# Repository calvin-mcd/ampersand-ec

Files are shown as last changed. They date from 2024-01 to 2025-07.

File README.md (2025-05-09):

# ampersand ec

This an open-source, experimental 2-layer EC pcb for the Ampersand keyboard designed by whitefacemountain. Ampersand is a gummyworm mounted 13.5u keyboard with minimum 40s support needed.

The firmware has been adapted by whitefacemountain and is based on [cipulot](https://cipulot.squarespace.com/)'s Menhir firmware.

## Disclaimer:

*As the Ampersand case is designed for a MX pcb using an oring, this EC pcb requires the use of [EC naevies](https://keyboardtreehouse.com/products/naevies-ec-switches) switches. Other EC switches might only work with heavy modifications of the outer housings.*

## Layout

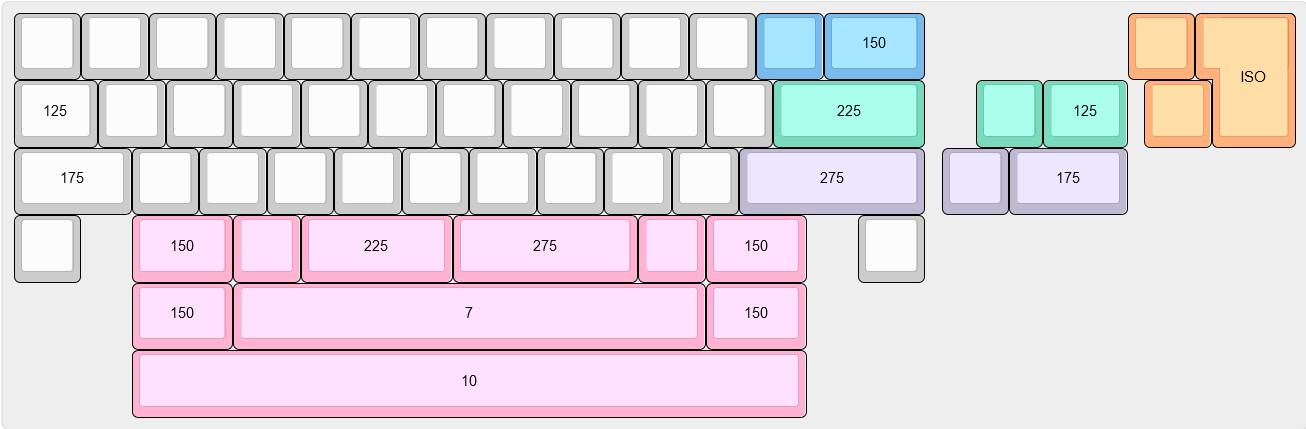
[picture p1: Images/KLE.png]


[Link](http://www.keyboard-layout-editor.com/#/gists/8dab2e8f328350c2c207f04be2b3e7d4)

There is currently only one naevies switch plate (7u, ansi, split right shift) available. More can be made available on request.

## To do

- [ ] order & test the revision (to eliminate an error with the bottom right control switch which is currently continuously triggered)

## Disclaimer

Please note that this project is a work in progress with no guarantees of a working outcome. No-one involved in this project is responsible for any usage issues that may arise. However, feel free to edit, modify and otherwise utilise these files.

## License

This project is released under the GPL v3 License. Please refer to the LICENCE file.

## Credits

As always big thanks also to the many people who inspired and helped with this board!

Any questions, contact Calvin0563 on Discord.

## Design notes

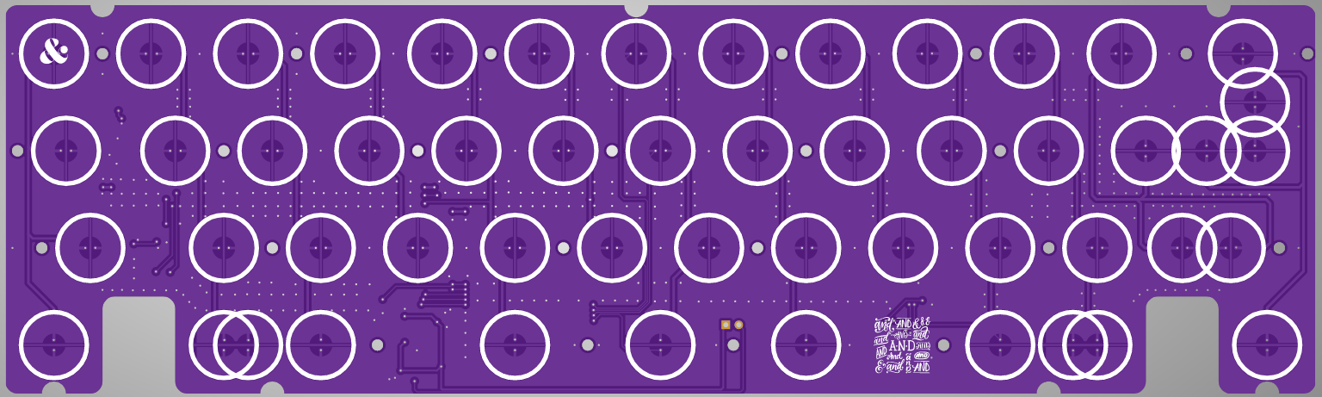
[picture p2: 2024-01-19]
Images/top.png

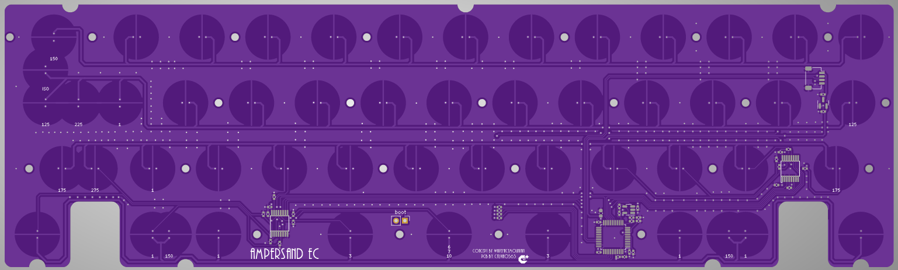
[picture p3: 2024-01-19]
Images/bottom.png

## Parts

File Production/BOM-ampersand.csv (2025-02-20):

Comment | Designator | Footprint | LCSC | Quantity
1k | R12 | R_0402_1005Metric | C11702 | 1
OPA354 | U4 | SOT-23-5 | C13388 | 1
220pF NP0 | C13 | C_0402_1005Metric | C1530 | 1
JST SH | J1 | JST_SH_SM04B-SRSS-TB_1x04-1MP_P1.00mm_Horizontal | C160404 | 1
100 | R1,R2,R3,R4 | R_0402_1005Metric | C25076 | 4
100k | R10,R11,R14,R15,R16,R17,R18,R19,R20,R21,R6,R7,R8,R9 | R_0402_1005Metric | C25741 | 14
10k | R5 | R_0402_1005Metric | C25744 | 1
100nF | C1,C11,C12,C14,C2,C3,C4,C6,C8 | C_0402_1005Metric | C307331 | 9
1uF | C10,C7,C9 | C_0402_1005Metric | C52923 | 3
XC6206PxxxMR-Regulator_Linear | U2 | SOT-23 | C5446 | 1
74HC4051 | U3,U5 | TSSOP16 | C5645 | 2
STM32F072CBT6 | U1 | LQFP-48_7x7mm_P0.5mm | C81720 | 1
10uF | C5 | C_0603_1608Metric | C96446 | 1

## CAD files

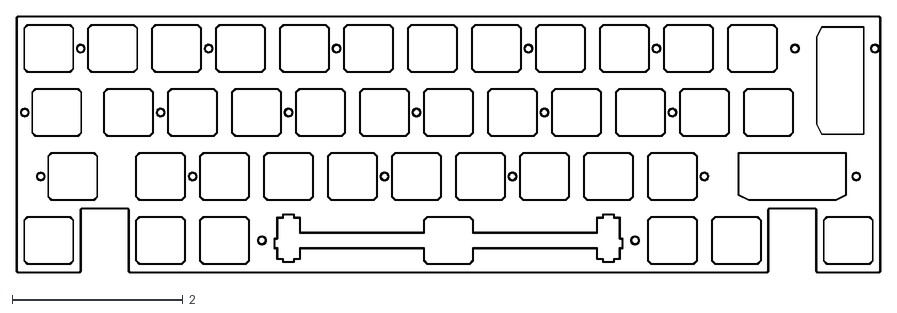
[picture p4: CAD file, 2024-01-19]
Production/Plates/6u ISO big mods-Edge_Cuts.dxf
10.1 x 3.01

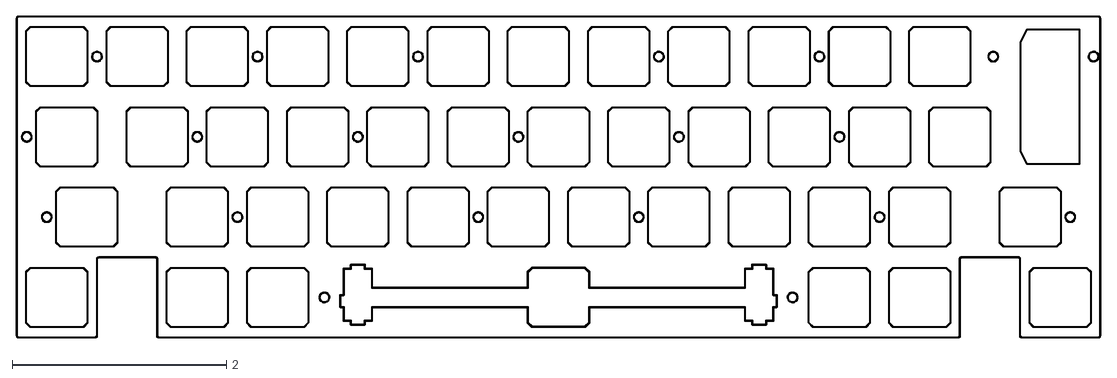
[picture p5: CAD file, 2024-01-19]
Production/Plates/6u ISO small mods-Edge_Cuts.dxf
10.1 x 3.01

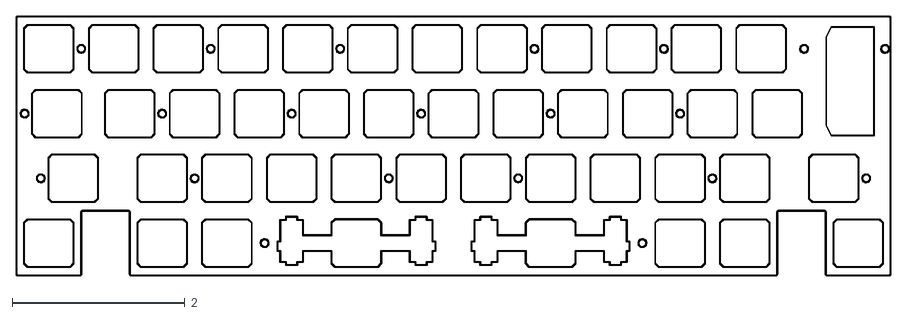
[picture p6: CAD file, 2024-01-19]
Production/Plates/3u ISO small mods-Edge_Cuts.dxf
10.1 x 3.01

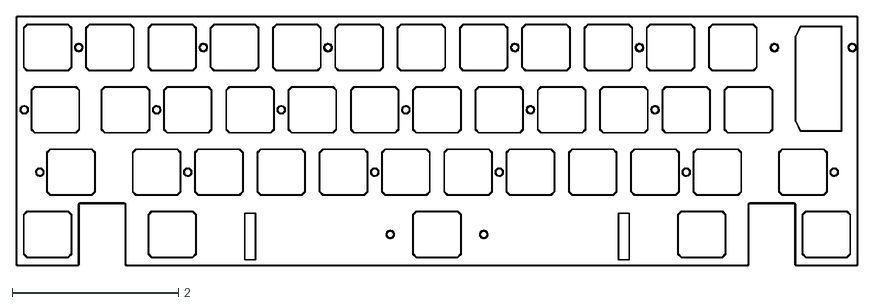
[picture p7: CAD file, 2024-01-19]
Production/Plates/7u ISO small mods-Edge_Cuts.dxf
10.1 x 3.01

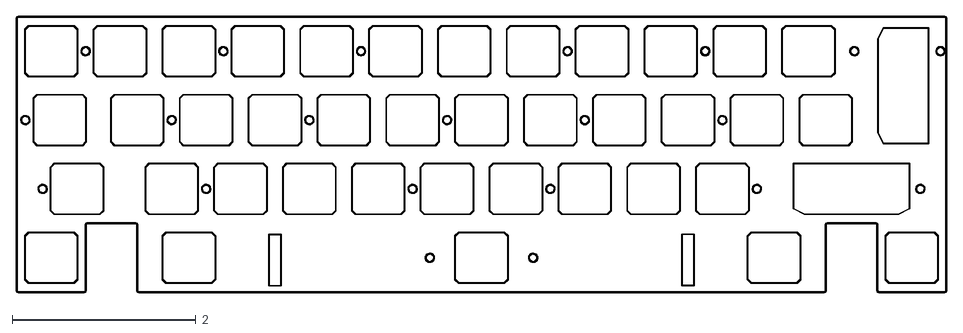
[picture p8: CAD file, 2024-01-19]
Production/Plates/7u ISO big mods-Edge_Cuts.dxf
10.1 x 3.01

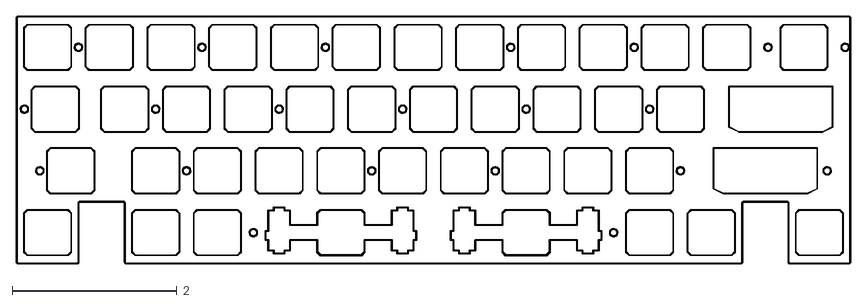
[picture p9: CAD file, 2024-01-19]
Production/Plates/3u big mods-Edge_Cuts.dxf
10.1 x 3.01

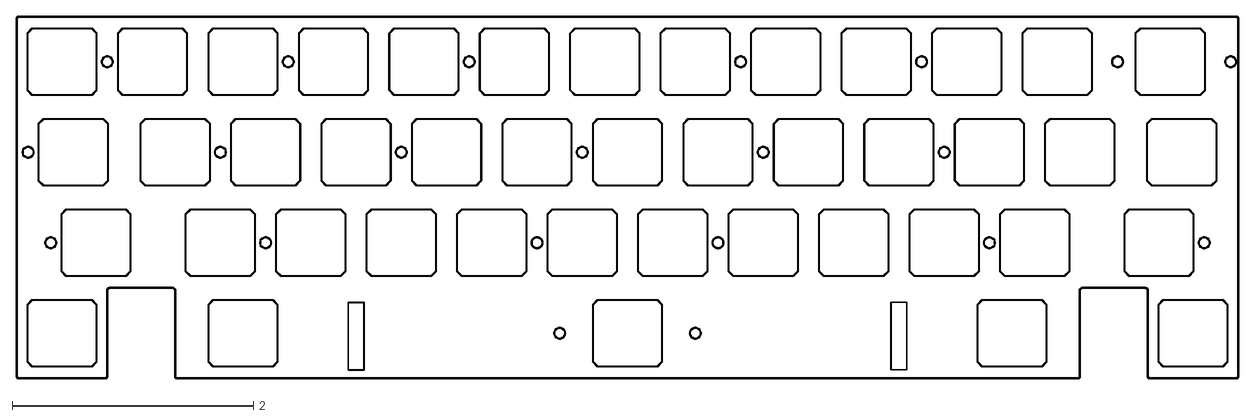
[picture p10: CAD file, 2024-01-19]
Production/Plates/7u small mods-Edge_Cuts.dxf
10.1 x 3.01

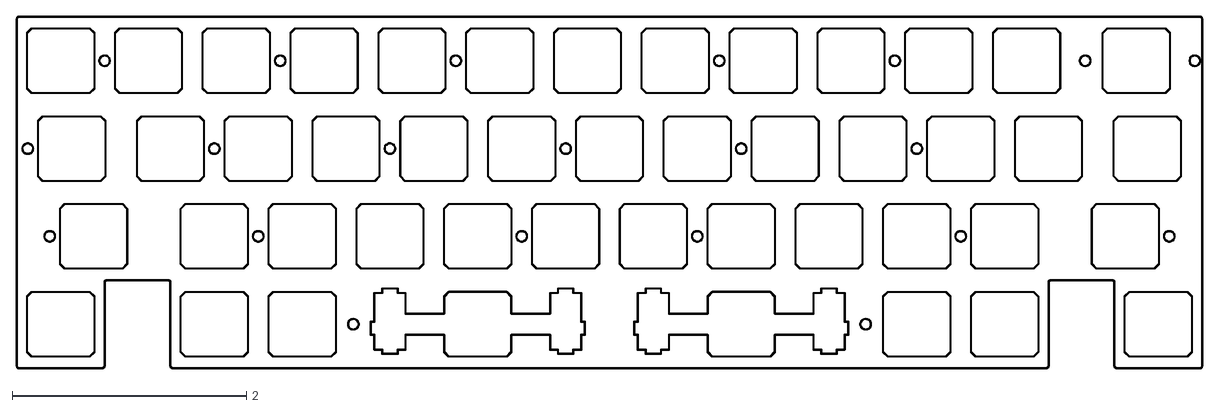
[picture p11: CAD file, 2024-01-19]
Production/Plates/3u small mods-Edge_Cuts.dxf
10.1 x 3.01

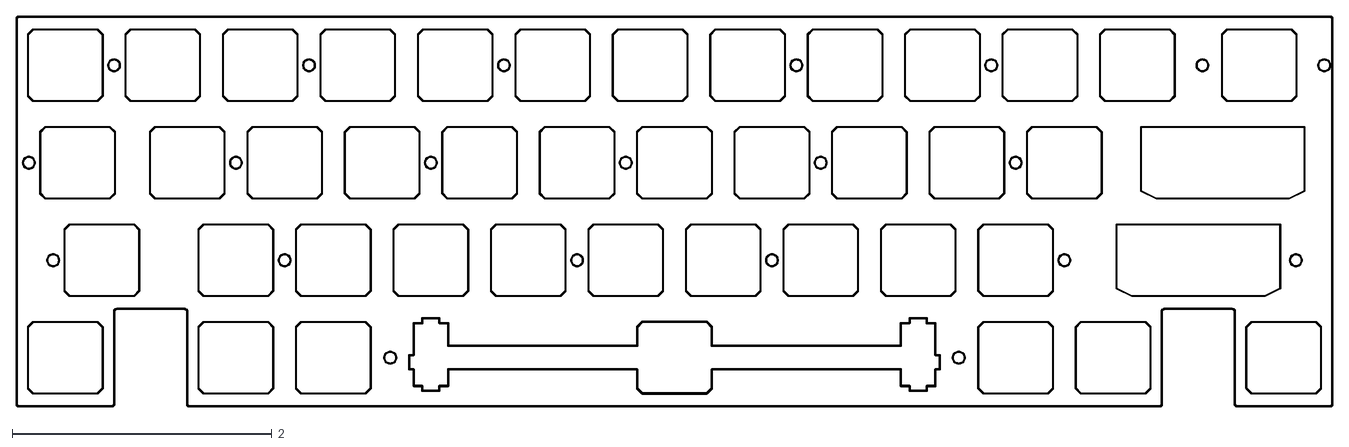
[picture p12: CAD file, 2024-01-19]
Production/Plates/6u big mods-Edge_Cuts.dxf
10.1 x 3.01

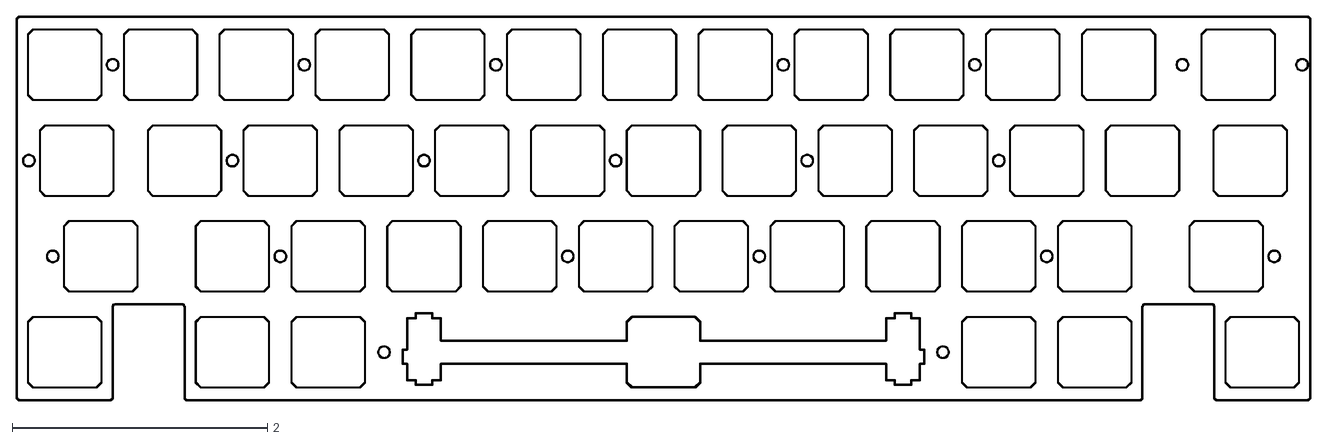
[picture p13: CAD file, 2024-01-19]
Production/Plates/6u small mods-Edge_Cuts.dxf
10.1 x 3.01

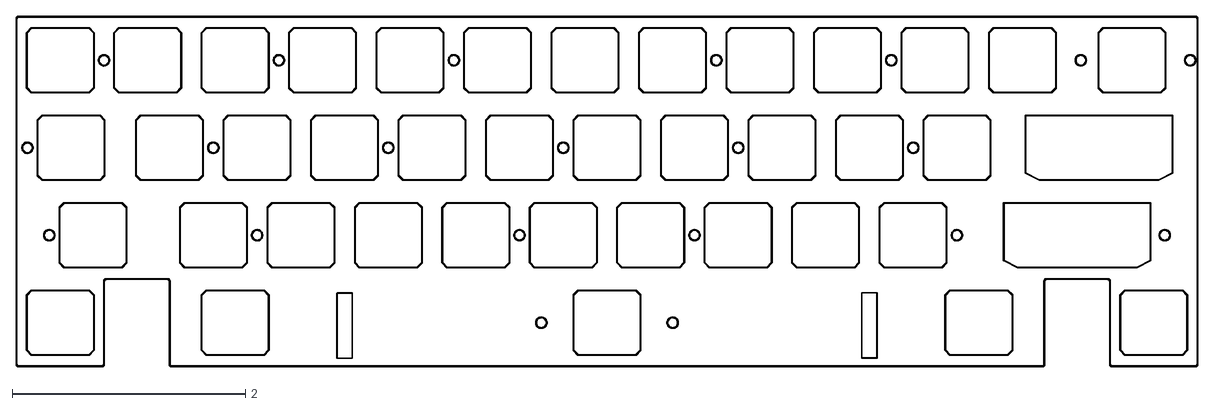
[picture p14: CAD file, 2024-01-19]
Production/Plates/7u big mods-Edge_Cuts.dxf
10.1 x 3.01

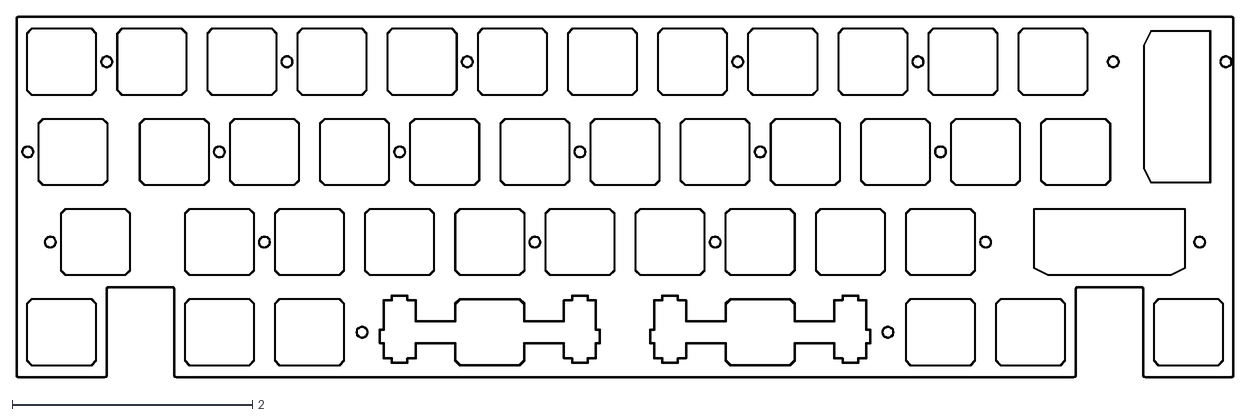
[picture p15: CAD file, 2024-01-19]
Production/Plates/3u ISO big mods-Edge_Cuts.dxf
10.1 x 3.01

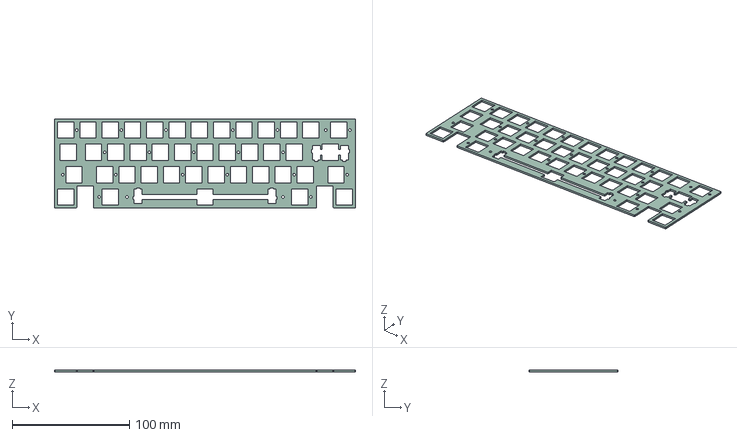
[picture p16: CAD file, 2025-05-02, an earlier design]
Project/Plates/naevies plate old.step
257.2 x 76.2 x 1.60 mm

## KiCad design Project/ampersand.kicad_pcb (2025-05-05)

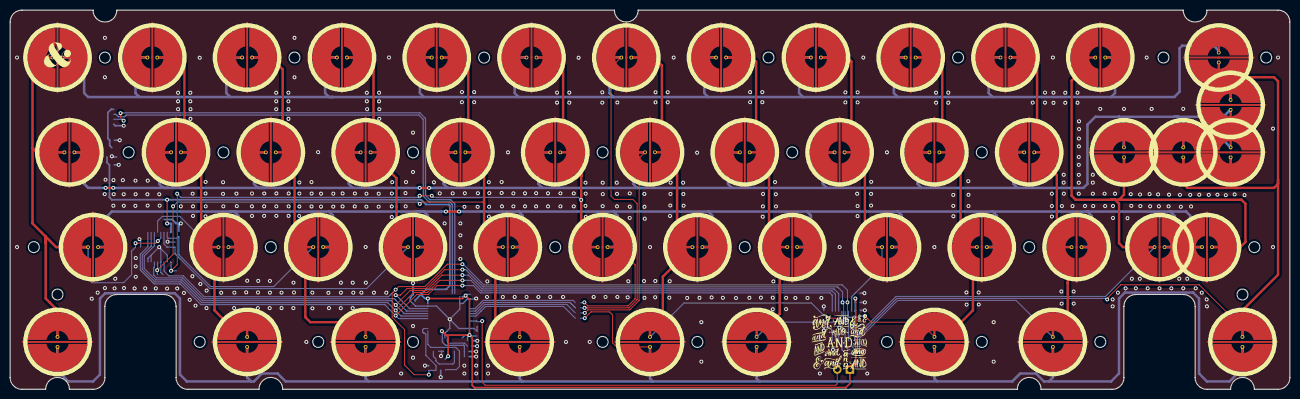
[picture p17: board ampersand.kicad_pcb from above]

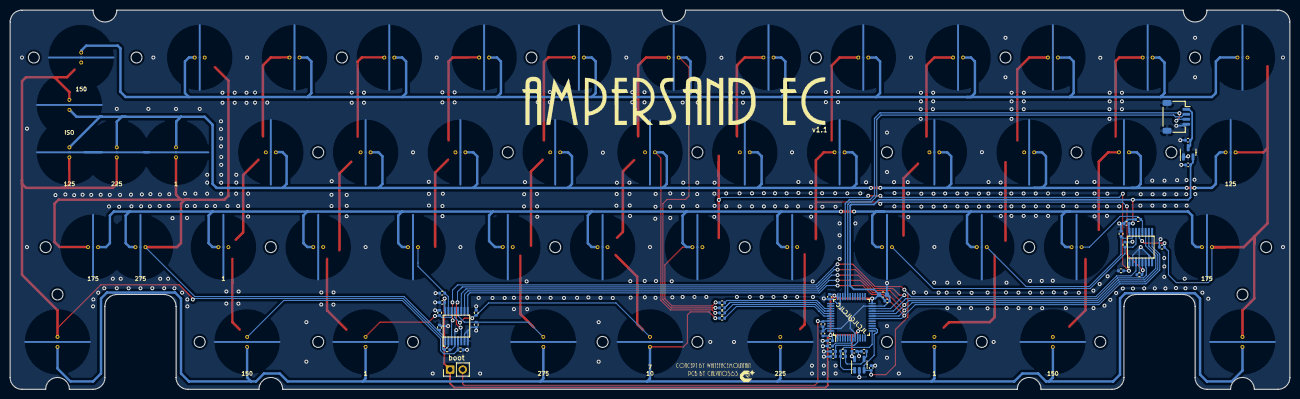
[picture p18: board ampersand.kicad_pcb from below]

Board: 2 copper layers, 257.2 x 76.2 mm, 121 parts (42 on the bottom side), 36 nets.

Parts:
C1, C2, C3, C4, C6, C8, C11, C12, C14: 100nF; C_0402_1005Metric
C5: 10uF; C_0603_1608Metric
C7, C9, C10: 1uF; C_0402_1005Metric
C13: 220pF NP0; C_0402_1005Metric
H1, H2, H3, H4, H5, H6, H7, H8, H9, H10, H11, H12, H13, H14, H15, H16, H17, H18, H19, H20, H21, H22, H23, H24, H25, H26, H27, H28, H29: MountingHole; HOLE_M2 (no arrow)
J1: JST SH; JST_SH_SM04B-SRSS-TB_1x04-1MP_P1.00mm_Horizontal
R1, R2, R3, R4: 100; R_0402_1005Metric
R5: 10k; R_0402_1005Metric
R6, R7, R8, R9, R10, R11, R14, R15, R16, R17, R18, R19, R20, R21: 100k; R_0402_1005Metric
R12: 1k; R_0402_1005Metric
R13: DNP; R_0402_1005Metric
SW1: DFU; PinHeader_1x02_P2.54mm_Vertical
SW_EC1, SW_EC2, SW_EC3, SW_EC4, SW_EC5, SW_EC6, SW_EC7, SW_EC8, SW_EC9, SW_EC10, SW_EC11, SW_EC12, SW_EC13, SW_EC14, SW_EC15, SW_EC16, SW_EC17, SW_EC18, SW_EC19, SW_EC20, SW_EC21, SW_EC22, SW_EC23, SW_EC24, SW_EC26, SW_EC27, SW_EC28, SW_EC29, SW_EC30, SW_EC31, SW_EC32, SW_EC33, SW_EC34, SW_EC35, SW_EC36, SW_EC37, SW_EC38, SW_EC39, SW_EC40, SW_EC41, SW_EC42, SW_EC43, SW_EC44, SW_EC45, SW_EC47, SW_EC48, SW_EC49, SW_EC50: Topre; ecs_pad_1U_no_ring
SW_EC25, SW_EC46: Topre; ecs_pad_1U_no_ring_1u_edge_cut
U1: STM32F072CBT6; LQFP-48_7x7mm_P0.5mm
U2: XC6206PxxxMR-Regulator_Linear; SOT-23
U3, U5: 74HC4051; TSSOP16
U4: OPA354; SOT-23-5

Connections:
+3V3: C1.1, C2.1, C3.1, C4.1, C5.1, C6.1, C7.1, C10.2, C11.2, C12.2, C14.2, SW1.1, U1.1 (VBAT), U1.9 (VDDA), U1.24 (VDD), U1.36 (VDDIO2), U1.48 (VDD), U2.2 (VO), U3.16 (VCC), U4.5 (V+), U5.16 (VCC)
+5V: C9.2, J1.1, U2.3 (VI)
ADC: R11.1, R13.1, U1.13 (PA3), U4.1
AMUX_SEL_0: U1.20 (PB2), U3.11 (S0), U5.11 (S0)
AMUX_SEL_1: U1.19 (PB1), U3.10 (S1), U5.10 (S1)
AMUX_SEL_2: U1.18 (PB0), U3.9 (S2), U5.9 (S2)
APLEX_EN_PIN_0: U1.21 (PB10), U3.6 (~E)
APLEX_EN_PIN_1: U1.22 (PB11), U5.6 (~E)
APLEX_OUT: C13.1, U1.14 (PA4), U3.3 (A), U4.3 (+), U5.3 (A)
BOOT0: R5.1, SW1.2, U1.44 (BOOT0)
COL0: R6.1, SW_EC1.1, SW_EC14.1, SW_EC27.1, SW_EC39.1, U3.13 (A0)
COL1: R9.1, SW_EC2.1, SW_EC15.1, SW_EC28.1, SW_EC40.1, U3.12 (A3)
COL2: R8.1, SW_EC3.1, SW_EC16.1, SW_EC29.1, SW_EC41.1, U3.15 (A2)
COL3: R7.1, SW_EC4.1, SW_EC17.1, SW_EC30.1, U3.14 (A1)
COL4: R10.1, SW_EC5.1, SW_EC18.1, SW_EC31.1, SW_EC43.1, U3.5 (A5)
COL5: R21.1, SW_EC6.1, SW_EC19.1, SW_EC32.1, U3.1 (A4)
COL6: R14.1, SW_EC7.1, SW_EC20.1, SW_EC33.1, SW_EC42.1, U5.13 (A0)
COL7: R17.1, SW_EC8.1, SW_EC21.1, SW_EC34.1, SW_EC45.1, U5.12 (A3)
COL8: R16.1, SW_EC9.1, SW_EC22.1, SW_EC35.1, U5.15 (A2)
COL9: R15.1, SW_EC10.1, SW_EC23.1, SW_EC36.1, SW_EC48.1, U5.14 (A1)
COL10: R18.1, SW_EC11.1, SW_EC24.1, SW_EC37.1, SW_EC49.1, U5.5 (A5)
COL11: R19.1, SW_EC12.1, SW_EC25.2, SW_EC38.1, SW_EC47.1, U5.1 (A4)
COL12: R20.1, SW_EC13.1, SW_EC26.1, SW_EC44.1, SW_EC46.1, SW_EC50.1, U5.2 (A6)
D_N: J1.2, U1.32 (PA11)
D_P: J1.3, U1.33 (PA12)
GND: C1.2, C2.2, C3.2, C4.2, C5.2, C6.2, C7.2, C8.2, C9.1, C10.1, C11.1, C12.1, C13.2, C14.1, J1.4, J1.MP (MountPin), R5.2, R6.2, R7.2, R8.2, R9.2, R10.2, R12.2, R14.2, R15.2, R16.2, R17.2, R18.2, R19.2, R20.2, R21.2, SW_EC1.3 (SG), SW_EC2.3 (SG), SW_EC3.3 (SG), SW_EC4.3 (SG), SW_EC5.3 (SG), SW_EC6.3 (SG), SW_EC7.3 (SG), SW_EC8.3 (SG), SW_EC9.3 (SG), SW_EC10.3 (SG), SW_EC11.3 (SG), SW_EC12.3 (SG), SW_EC13.3 (SG), SW_EC14.3 (SG), SW_EC15.3 (SG), SW_EC16.3 (SG), SW_EC17.3 (SG), SW_EC18.3 (SG), SW_EC19.3 (SG), SW_EC20.3 (SG), SW_EC21.3 (SG), SW_EC22.3 (SG), SW_EC23.3 (SG), SW_EC24.3 (SG), SW_EC25.3 (SG), SW_EC26.3 (SG), SW_EC27.3 (SG), SW_EC28.3 (SG), SW_EC29.3 (SG), SW_EC30.3 (SG), SW_EC31.3 (SG), SW_EC32.3 (SG), SW_EC33.3 (SG), SW_EC34.3 (SG), SW_EC35.3 (SG), SW_EC36.3 (SG), SW_EC37.3 (SG), SW_EC38.3 (SG), SW_EC39.3 (SG), SW_EC40.3 (SG), SW_EC41.3 (SG), SW_EC42.3 (SG), SW_EC43.3 (SG), SW_EC44.3 (SG), SW_EC45.3 (SG), SW_EC46.3 (SG), SW_EC47.3 (SG), SW_EC48.3 (SG), SW_EC49.3 (SG), SW_EC50.3 (SG), U1.8 (VSSA), U1.23 (VSS), U1.35 (VSS), U1.47 (VSS), U2.1 (GND), U3.2 (A6), U3.4 (A7), U3.7 (VEE), U3.8 (GND), U4.2 (V-), U5.4 (A7), U5.7 (VEE), U5.8 (GND)
NRST: C8.1, U1.7 (NRST)
unnamed: R4.1, U1.39 (PB3)
unnamed: R3.1, U1.40 (PB4)
unnamed: R2.1, U1.41 (PB5)
unnamed: R1.1, U1.42 (PB6)
unnamed: R11.2, R12.1, R13.2, U4.4 (-)
ROW0: R3.2, SW_EC1.2, SW_EC2.2, SW_EC3.2, SW_EC4.2, SW_EC5.2, SW_EC6.2, SW_EC7.2, SW_EC8.2, SW_EC9.2, SW_EC10.2, SW_EC11.2, SW_EC12.2, SW_EC13.2
ROW1: R2.2, SW_EC14.2, SW_EC15.2, SW_EC16.2, SW_EC17.2, SW_EC18.2, SW_EC19.2, SW_EC20.2, SW_EC21.2, SW_EC22.2, SW_EC23.2, SW_EC24.2, SW_EC25.1, SW_EC26.2, SW_EC44.2, SW_EC46.2
ROW2: R4.2, SW_EC27.2, SW_EC28.2, SW_EC29.2, SW_EC30.2, SW_EC31.2, SW_EC32.2, SW_EC33.2, SW_EC34.2, SW_EC35.2, SW_EC36.2, SW_EC37.2, SW_EC38.2, SW_EC47.2
ROW3: R1.2, SW_EC39.2, SW_EC40.2, SW_EC41.2, SW_EC42.2, SW_EC43.2, SW_EC45.2, SW_EC48.2, SW_EC49.2, SW_EC50.2

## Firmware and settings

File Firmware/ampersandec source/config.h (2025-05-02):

#pragma once

#define MATRIX_ROWS 4
#define MATRIX_COLS 13

#define MATRIX_ROW_PINS \
    { B4, B5, B3, B6 }

#define AMUX_COUNT 2
#define AMUX_MAX_COLS_COUNT 7

#define AMUX_EN_PINS \
    { B10, B11 }

#define AMUX_SEL_PINS \
    { B2, B1, B0 }

#define AMUX_COL_CHANNELS_SIZES \
    { 6, 7 }

#define AMUX_0_COL_CHANNELS \
    { 0, 3, 2, 1, 5, 4 }

#define AMUX_1_COL_CHANNELS \
    { 0, 3, 2, 1, 5, 4, 6 }

#define AMUX_COL_CHANNELS AMUX_0_COL_CHANNELS, AMUX_1_COL_CHANNELS

#define DISCHARGE_PIN A4
#define ANALOG_PORT A3

#define DEFAULT_ACTUATION_MODE 0
#define DEFAULT_MODE_0_ACTUATION_LEVEL 550
#define DEFAULT_MODE_0_RELEASE_LEVEL 500
#define DEFAULT_MODE_1_INITIAL_DEADZONE_OFFSET DEFAULT_MODE_0_ACTUATION_LEVEL
#define DEFAULT_MODE_1_ACTUATION_OFFSET 70
#define DEFAULT_MODE_1_RELEASE_OFFSET 70
#define DEFAULT_EXTREMUM 1023
#define EXPECTED_NOISE_FLOOR 0
#define NOISE_FLOOR_THRESHOLD 50
#define BOTTOMING_CALIBRATION_THRESHOLD 50
#define DEFAULT_NOISE_FLOOR_SAMPLING_COUNT 30
#define DEFAULT_BOTTOMING_READING 1023
#define DEFAULT_CALIBRATION_STARTER true

#define DISCHARGE_TIME 10

#define EECONFIG_KB_DATA_SIZE 109

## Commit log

2024-01-09 clean up
    [ampersand.kicad_pcb, ampersand.kicad_sch]
2024-01-13 plate work
    [EC matrix.kicad_sch, ampersand.kicad_sch, mounting holes.kicad_sch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]
2024-03-30 pcb & plate revisions & firmware
    [3u ISO big mods.kicad_pcb, 3u ISO small mods.kicad_pcb, 3u big mods.kicad_pcb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]
2024-03-31 bottom row change, plate update, firmware update
    [10u ISO big mods.kicad_pcb, 10u ISO small mods.kicad_pcb, 10u big mods.kicad_pcb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]
2024-05-30 update & backup
    [ampersand.kicad_sch]
2025-02-20 updated production files
    naevies plate added
    [BOM-ampersand.csv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]
2025-03-01 production files update
    [BOM-ampersand.csv]
2025-04-30 v1 production files
    [BOM-ampersand.csv, EC matrix.kicad_sch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]
2025-05-02 update
    error fixing
    [ampersand.kicad_pcb]
2025-05-02 update production files
    [ampersand-B_Cu.gbr, ampersand-B_Mask.gbr, ampersand-B_Paste.gbr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]
2025-05-05 V1 completed
    [ampersand-B_Cu.gbr, ampersand-B_Mask.gbr, ampersand-B_Paste.gbr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]
